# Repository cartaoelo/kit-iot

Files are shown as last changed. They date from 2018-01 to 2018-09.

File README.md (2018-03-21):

# KIT ELO IOT

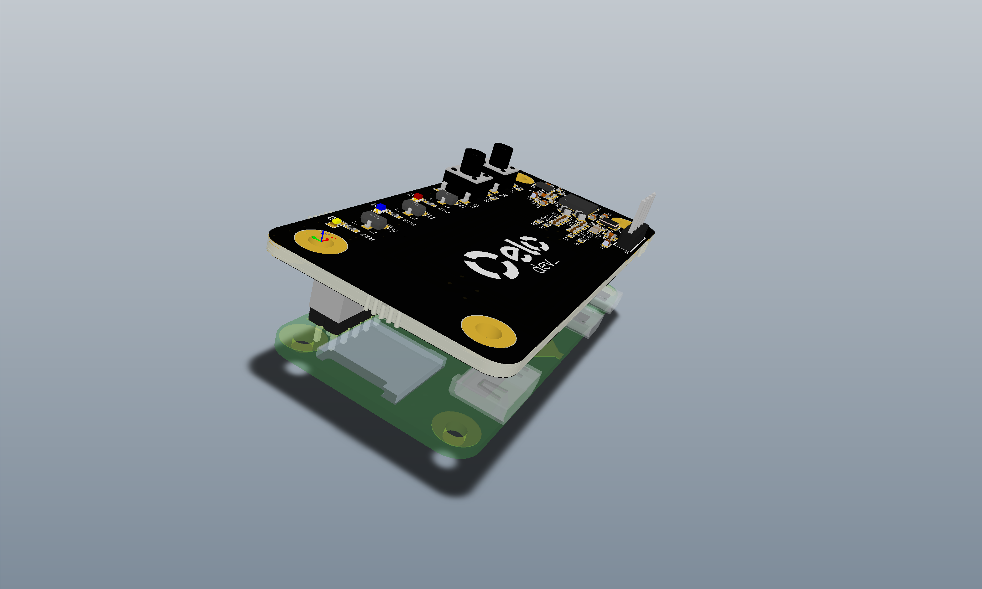
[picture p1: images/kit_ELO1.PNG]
Placa ELO + Raspberry Zero W

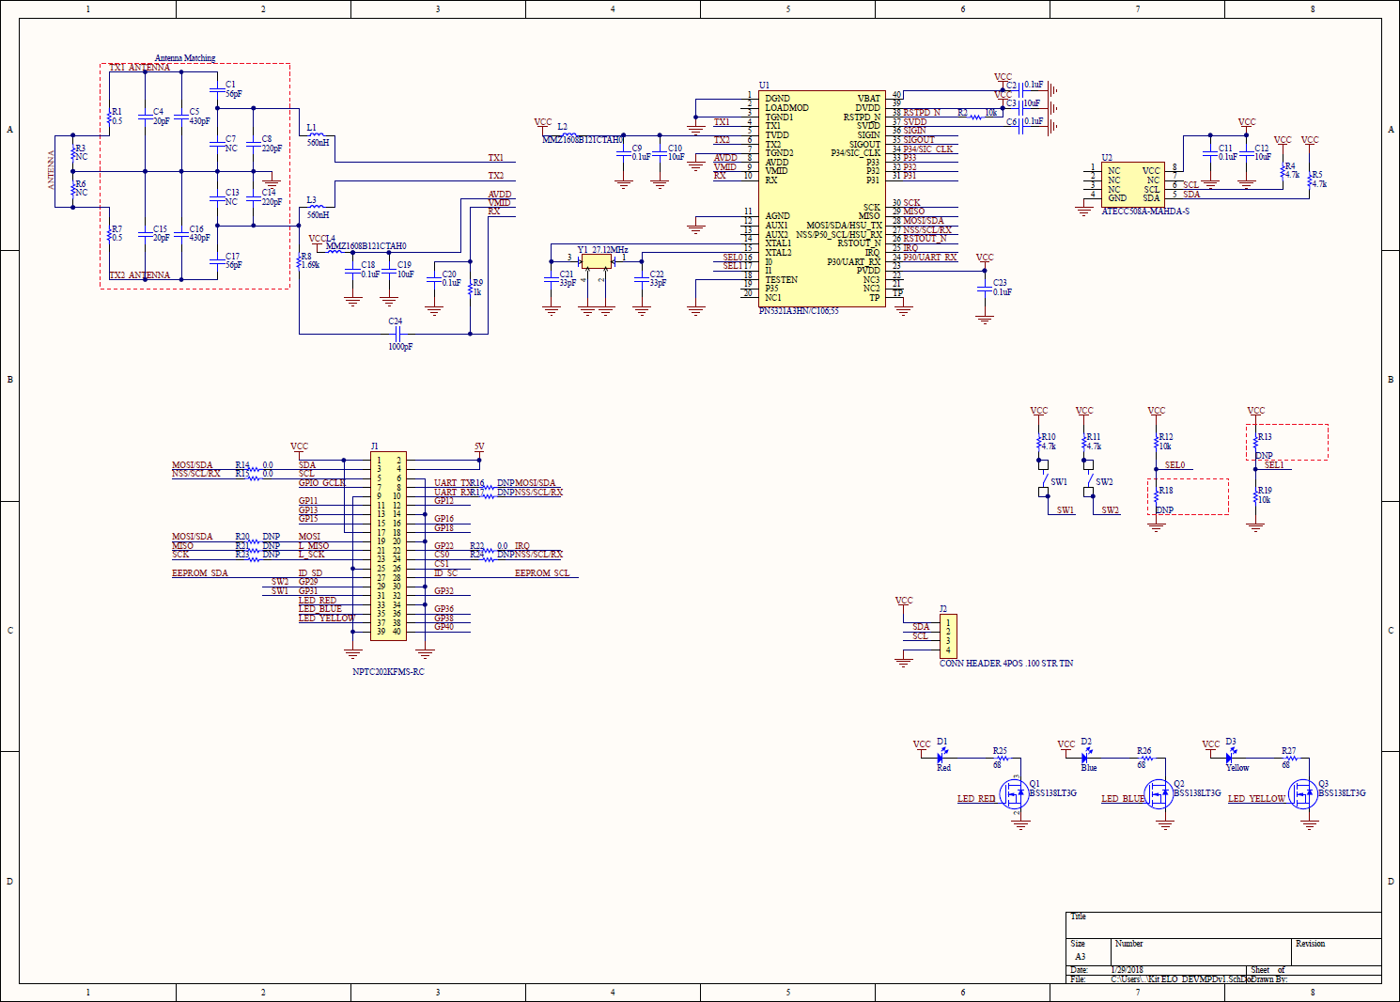
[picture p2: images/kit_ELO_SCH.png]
Placa ELO schematic


# PN532

**INTRODUÇÃO**

Este documento explica como utilizar o leitor NFC PN532 programando em Node.js.

### O que é NFC? 
>Near Field Communication
>É uma tecnologia que permite a troca de informações sem fio
>entre dispositivos, sendo necessária apenas uma aproximação
>física. A novidade teve origem no padrão RFID (Radio Frequency 
>Identification), mas se distanciou deste ao limitar o campo de 
>atuação de freqüências para uma distância de até 10 centímetros,
> objetivando tornar-se mais segura.

**ARQUIVOS NECESSÁRIOS**

Será necessário baixar a biblioteca modificada no github da elo-dev.

```sh
pi@raspberrypi:~ $ git clone https://github.com/cartaoelo/kit-iot.git
```

**INSTALAÇÃO**

O nodejs já vem instalado na raspberry em algumas imagens disponíveis no site do fabricante. Caso a versão do sistema operacional não possua o software instalado, deverá ser feita a instalação. Depois de instalar o nodejs, devemos instalar os pacotes npm necessários para que o exemplo funcione.
```sh
pi@raspberrypi:~ $ sudo apt-get install nodejs
pi@raspberrypi:~/kit-iot $ npm install --save
```

**DETECTANDO O PN532**

O PN532 será utilizado com comunicação i2c ligado no barramento padrão da raspberry  /dev/i2c-1. Para detectar o PN532 no barramento i2c será instalado o software i2c-tools. 

```sh
pi@raspberrypi:~ $ sudo apt-get install i2c-tools 
pi@raspberrypi:~ $ i2cdetect -y 1
    0  1  2  3  4  5  6  7  8  9  a  b  c  d  e  f
00:          -- -- -- -- -- -- -- -- -- -- -- -- --
10: -- -- -- -- -- -- -- -- -- -- -- -- -- -- -- --
20: -- -- -- -- 24 -- -- -- -- -- -- -- -- -- -- --
30: -- -- -- -- -- -- -- -- -- -- -- -- -- -- -- --
40: -- -- -- -- -- -- -- -- -- -- -- -- -- -- -- --
50: -- -- -- -- -- -- -- -- -- -- -- -- -- -- -- --
60: 60 -- -- -- -- -- -- -- -- -- -- -- -- -- -- --
70: -- -- -- -- -- -- -- -- 
```

O endereço i2c do PN532 é 0x24, o outro endereço exibido no log do comando é o chip de autenticação ATECC508A também instalado no kit-iot da ELO.

**EXEMPLO**

Depois de clonar o diretório do projeto, basta rodar o código exemplo.
```sh
pi@raspberrypi:~/kit-iot $ node example.js
READY
Firmware:  { IC: 50, Ver: 1, Rev: 6, Support: 7 }
Listen for card read event ...
1516380276255 'UID:' '04:96:a5:89:ba:53:5b'
1516380276583 'UID:' '04:96:a5:89:ba:53:5b'
1516380276875 'UID:' '04:96:a5:89:ba:53:5b'
1516380277164 'UID:' '04:96:a5:89:ba:53:5b' 
```

# ATECC508A - CONFIGURAÇÃO

**INTRODUÇÃO**

Este documento explica como utilizar o software Cryptotronix EClet para configurar o chip Atmel ATECC508A em uma raspberry pi.

**ARQUIVOS NECESSÁRIOS**

Será necessário o download do driver:
https://github.com/cryptotronix/EClet

```sh
 pi@raspberrypi:~ $ git clone https://github.com/cryptotronix/EClet.git
```

**INSTALAÇÃO**

Instale build-essential, autotools-dev, automake, autoconf, libtool, libxml2-dev, check, texinfo, and libgcrypt (libgcrypt11-dev on Debian variants)

```sh
pi@raspberrypi:~ $ sudo apt-get install build-essential autotools-dev automake autoconf libtool libxml2-dev check texinfo libgcrypt11-dev
```

Após isso rode o arquivo ./autogen.sh . 

Isso irá gerar o arquivo README necessário a partir do arquivo README.md assim como a versão beta requerida da biblioteca baixada anteriormente.

```sh
pi@raspberrypi:~ $ sudo ./autogen.sh
pi@raspberrypi:~ $ sudo make install
```

**CONFIGURAÇÔES INICIAIS**

Você tera que ter acesso ao barramento i2c da Raspberry ` /dev/i2c* `. 

É possível mudar isto adicionando seu usuário para o grupo I2C utilizando: `sudo usermod -aG i2c user ` ou ` sudo chmod o+rw /dev/i2c* ` .

Lista de comandos:

**eclet state** : verifica se está em estado de fábrica.

```sh
pi@raspberrypi:~ $ eclet state
Factory 
```

**eclet  personalize** : em caso de sucesso este comando não retorna nada, sua função é configurar todos os slots (0-16) para a chave privada. 

O slot 8 é reservado para uso futuro. 

```sh
pi@raspberrypi:~ $ eclet personalize 
pi@raspberrypi:~ $ eclet state 
Personalized
```

**eclet  random** : Até que você tenha personalizado o seu dispositivo, o gerador de número aleatório irá retornar um número com padrões contendo FF e 00. 

```sh
pi@raspberrypi:~ $ eclet random
7E74FBFE17A10026124B092C9727416D6C28B38FA5D598E0711A9FCDFCDEC408 
```

**eclet  serial-num** : Retorna o serial do dispositivo.

```sh
pi@raspberrypi:~ $ eclet serial-num
0123XXXXXXXXXXXXEE
```

**eclet  gen-key** : Irá criar uma chave privada com 256 bits e irá retornar uma chave pública de formato 0x04 + X +Y. 

Caso o comando seja dado mais vezes a chave pública irá ser alterada.

```sh
pi@raspberrypi:~ $ eclet gen-key
042A02563C69C4CB5356BD8BBA96B1559D5FE799B6C497B128F42F8CB31FF751BF40361F0970DF48979B3E18A1039047299A1C3D7B809EAA2F844F0D75C479BDB9
```

**eclet  sign -f ChangeLog** : Cria uma assinatura ECDSA. 

O arquivo pode ser especificado com -f.

```sh
pi@raspberrypi:~/Eclet $ eclet sign -f ChangeLog 5D1BD52DD2294CA1518E2520CFBF518AD6DD48AA57978BCAF91919E51E5FE3CA2B1EFC8427AC7EC499DF340B197319545FCB``2A7F87D981F6712365CF3E6872B3
```

**eclet  verify** : Verifica a assinatura ECDSA usada no dispositivo. 

Se estiver correta, nada acontecerá, caso contrário é reportada uma mensagem de falha na verificação.

```sh
pi@raspberrypi:~/Eclet $ eclet verify -f ChangeLog -–signature 5D1BD52DD2294CA1518E2520CFBF518AD6DD48AA57978BCAF91919E51E5FE3CA2B1EFC8427AC7EC499DF340B197319545FCB2A7F87D981F6712365CF3E6872B3 -–public-key 04DD24F3770BD11A6A465F37D1D6CEEA58F8B8E1B85A5D3D665A0382BCBCDDC81321458F8A4FE5777BA0D508780A2476A23434B89BE2BBD5B8CF574348A15F1982
```

**eclet  offline-verify-sign** : Verifica a assinatura ECDSA usada, sem a necessidade do dispositivo. 

Se estiver correta, nada acontecerá, caso contrário é reportada uma mensagem de falha na verificação.

```sh
pi@raspberrypi:~/Eclet $ eclet offline-verify-sign -f ChangeLog -–signature 5D1BD52DD2294CA1518E2520CFBF518AD6DD48AA57978BCAF91919E51E5FE3CA2B1EFC8427AC7EC499DF340B197319545FCB2A7F87D981F6712365CF3E6872B3 -–public-key 04DD24F3770BD11A6A465F37D1D6CEEA58F8B8E1B85A5D3D665A0382BCBCDDC81321458F8A4FE5777BA0D508780A2476A23434B89BE2BBD5B8CF574348A15F1982
```

**OPÇÕES**

As opções podem ser visualizadas utilizando o comando –-help .

**LICENÇA**

Este produto é _**open source**_ de software distribuído sob a licença GPLv3 e hardware sob a licença CERN OHL v1.2!

EClet foi escrito por Cryptotronix, e distribuído sob licença GPLv3.

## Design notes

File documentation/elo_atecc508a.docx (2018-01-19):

ATECC508A

# INTRODUÇÃO

Este documento explica como utilizar o software Cryptotronix EClet para configurar o chip Atmel ATECC508A em uma raspberry pi.

# ARQUIVOS NECESSÁRIOS

Será necessário o download do driver:

https://github.com/cryptotronix/EClet

pi@raspberrypi:~ $ git clone https://github.com/cryptotronix/EClet.git

INSTALAÇÃO

Instale build-essential, autotools-dev, automake, autoconf, libtool, libxml2-dev, check, texinfo, and libgcrypt (libgcrypt11-dev on Debian variants)

pi@raspberrypi:~ $ sudo apt-get install build-essential autotools-dev automake autoconf libtool libxml2-dev check texinfo libgcrypt11-dev

Após isso rode o arquivo ./autogen.sh . Isso irá gerar o arquivo README necessário a partir do arquivo README.md assim como a versão beta requerida da biblioteca baixada anteriormente.

pi@raspberrypi:~ $ sudo ./autogen.sh

pi@raspberrypi:~ $ sudo make install

# CONFIGURAÇÔES INICIAIS

Inicialmente é necessário executar /dev/i2c* para o acesso. É possível mudar isto adicionando seu usuário para o grupo I2C utilizando: sudo usermod -aG i2c user ou sudo chmod o+rw /dev/i2c* .

Existem alguns comandos suportados:

eclet state : verifica se está em estado de fábrica.

pi@raspberrypi:~ $ eclet state

Factory

eclet personalize : em caso de sucesso este comando não retorna nada, sua função é configurar todos os slots (0-16) para a chave privada. O slot 8 é reservado para uso futuro.

pi@raspberrypi:~ $ eclet personalize

pi@raspberrypi:~ $ eclet state

Personalized

eclet random : Até que você tenha personalizado o seu dispositivo, o gerador de número aleatório irá retornar um número com padrões contendo FF e 00.

pi@raspberrypi:~ $ eclet random

7E74FBFE17A10026124B092C9727416D6C28B38FA5D598E0711A9FCDFCDEC408

eclet serial-num : Retorna o serial do dispositivo.

pi@raspberrypi:~ $ eclet serial-num

0123XXXXXXXXXXXXEE

eclet gen-key : Irá criar uma chave privada com 256 bits e irá retornar uma chave pública de formato 0x04 + X +Y. Caso o comando seja dado mais vezes a chave pública irá ser alterada.

pi@raspberrypi:~ $ eclet gen-key

042A02563C69C4CB5356BD8BBA96B1559D5FE799B6C497B128F42F8CB31FF751BF40361F0970DF48979B3E18A1039047299A1C3D7B809EAA2F844F0D75C479BDB9

eclet sign -f ChangeLog : Cria uma assinatura ECDSA. O arquivo pode ser especificado com -f.

pi@raspberrypi:~/Eclet $ eclet sign -f ChangeLog

5D1BD52DD2294CA1518E2520CFBF518AD6DD48AA57978BCAF91919E51E5FE3CA2B1EFC8427AC7EC499DF340B197319545FCB2A7F87D981F6712365CF3E6872B3

eclet verify : Verifica a assinatura ECDSA usada no dispositivo. Se estiver correta, nada acontecerá, caso contrário uma mensagem de falha na verificação acontecerá.

pi@raspberrypi:~/Eclet $ eclet verify -f ChangeLog -–signature 5D1BD52DD2294CA1518E2520CFBF518AD6DD48AA57978BCAF9191

9E51E5FE3CA2B1EFC8427AC7EC499DF340B197319545FCB2A7F87D981F6712365CF3E6872B3 -–public-key 04DD24F3770BD11A6A465F37D1D6CEEA58F8B8E

1B85A5D3D665A0382BCBCDDC81321458F8A4FE5777BA0D508780A2476A23434B89BE2BBD5B8CF574348A15F1982

eclet offline-verify-sign : Verifica a assinatura ECDSA usada, sem a necessidade do dispositivo. Se estiver correta, nada acontecerá, caso contrário uma mensagem de falha na verificação acontecerá.

pi@raspberrypi:~/Eclet $ eclet offline-verify-sign -f ChangeLog -–signature 5D1BD52DD2294CA1518E2520CFBF518AD6DD48AA

57978BCAF91919E51E5FE3CA2B1EFC8427AC7EC499DF340B197319545FCB2A7F87D981F6712365CF3E6872B3 -–public-key 04DD24F3770BD11A6A465F37D1

D6CEEA58F8B8E1B85A5D3D665A0382BCBCDDC81321458F8A4FE5777BA0D508780A2476A23434B89BE2BBD5B8CF574348A15F1982

# OPÇÕES

As opções podem ser visualizadas utilizando o comando –-help .

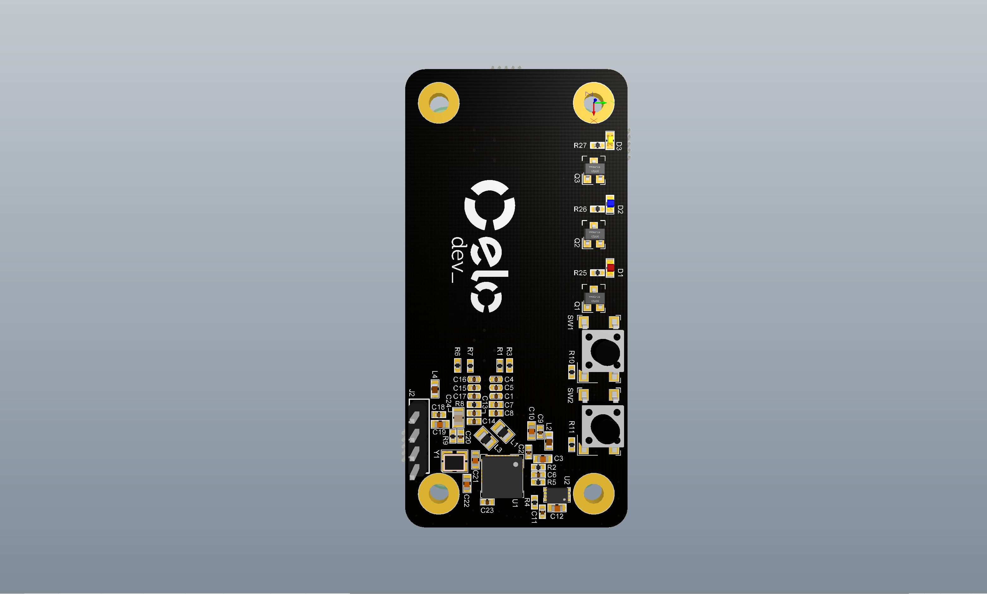
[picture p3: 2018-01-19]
images/kit_ELO2.PNG

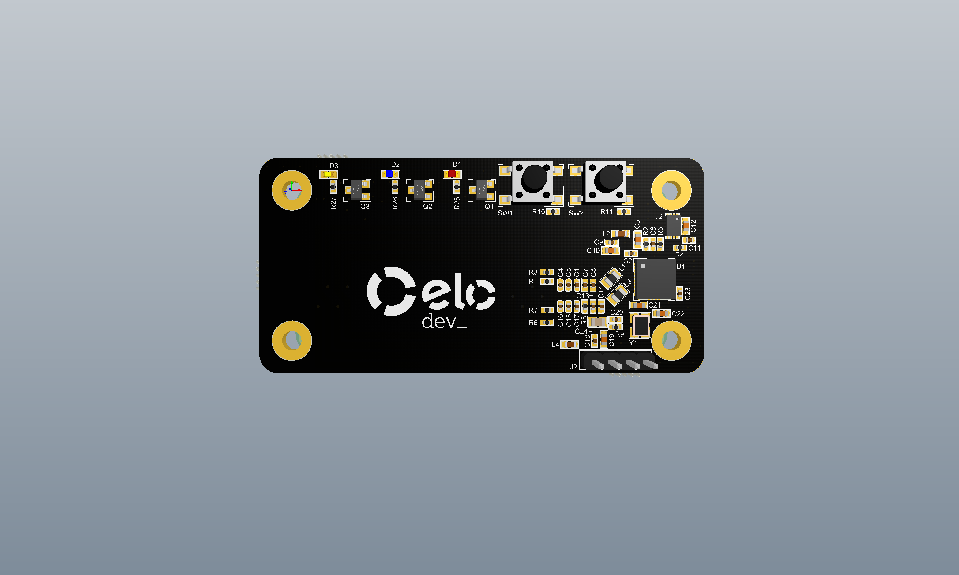
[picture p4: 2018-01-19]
images/kit_ELO3.PNG

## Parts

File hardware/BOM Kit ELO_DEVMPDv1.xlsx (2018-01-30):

Quantity | Designator | Description | Comment | Manufacturer | Manufacturer Part Number
2 | C1, C17 | CAP CER 56PF 50V C0G/NP0 0402 | 56pF | Vishay Vitramon | VJ0402D560JXAAJ
7 | C2, C6, C9, C11, C18, C20, C23 | CAP CER 0.1UF 10V X5R 0402 | 0.1uF | Murata Electronics North America | GRM155R61A104KA01D
4 | C3, C10, C12, C19 | CAP CER 10UF 16V X5R 0603 | 10uF | Murata Electronics North America | GRM188R61C106KAALD
2 | C4, C15 | CAP CER 20PF 50V C0G/NP0 0402 | 20pF | KEMET | C0402C200J5GACTU
2 | C5, C16 | CAP CER 430PF 50V C0G/NP0 0402 | 430pF | Murata Electronics North America | GRM1555C1H431GA01D
2 | C7, C13 | NC | NC | Murata Electronics North America | GRM155R61A104KA01D
2 | C8, C14 | CAP CER 220PF 50V C0G/NP0 0402 | 220pF | Samsung Electro-Mechanics | CL05C221JB5NNNC
2 | C21, C22 | CAP CER 33PF 50V C0G/NP0 0603 | 33pF | Murata Electronics North America | GRM1885C1H330JA01D
1 | C24 | CAP CER 1000PF 50V C0G/NP0 0805 | 1000pF | AVX Corporation | 08055A102GAT2A
1 | D1 | LED RED CLEAR 0603 SMD | Red | Lite-On Inc. | LTST-C190EKT
1 | D2 | LED BLUE CLEAR 0603 SMD | Blue | Lite-On Inc. | LTST-C193TBKT-5A
1 | D3 | LED YELLOW CLEAR 0603 SMD | Yellow | Lite-On Inc. | LTST-C191KSKT
1 | J1 | CONN FEMALE 40POS DL .1" TIN SMD | NPTC202KFMS-RC | Sullins Connector Solutions | NPTC202KFMS-RC
1 | J2 | CONN HEADER 4POS .100 STR TIN | CONN HEADER 4POS .100 STR TIN | Amphenol FCI | 68002-404HLF
2 | L1, L3 | FIXED IND 560NH 240MA 3.1 OHM | 560nH | Pulse Electronics Network | PE-0805CM561JTT
2 | L2, L4 | FERRITE BEAD 120 OHM 0603 1LN | MMZ1608B121CTAH0 | TDK Corporation | MMZ1608B121CTAH0
3 | Q1, Q2, Q3 | MOSFET N-CH 50V 200MA SOT-23 | BSS138LT3G | ON Semiconductor | BSS138LT3G
2 | R1, R7 | RES 0.5 OHM 1% 1/16W 0402 | 0.5 | Yageo | RL0402FR-070R5L
3 | R2, R12, R19 | RES SMD 10K OHM 1% 1/16W 0402 | 10k | Yageo | RC0402FR-0710KL
2 | R3, R6 | NC | NC | Yageo | RC0402FR-0710KL
4 | R4, R5, R10, R11 | RES SMD 4.7K OHM 5% 1/10W 0402 | 4.7k | Panasonic Electronic Components | ERJ-2GEJ472X
1 | R8 | RES SMD 1.69K OHM 1% 1/16W 0402 | 1.69k | Yageo | RC0402FR-071K69L
1 | R9 | RES SMD 1K OHM 5% 1/16W 0402 | 1k | Yageo | RC0402JR-071KL
8 | R13, R16, R17, R18, R20, R21, R23, R24 | RES SMD 0.0OHM JUMPER 1/16W 0402 | DNP | Rohm Semiconductor | MCR01MZPJ000
3 | R14, R15, R22 | RES SMD 0.0OHM JUMPER 1/16W 0402 | 0.0 | Rohm Semiconductor | MCR01MZPJ000
3 | R25, R26, R27 | RES SMD 68 OHM 5% 1/10W 0402 | 68 | Panasonic Electronic Components | ERJ-2GEJ680X
2 | SW1, SW2 | SWITCH TACTILE SPST-NO 0.05A 12V | PTS645SL50SMTR92 LFS | C&K | PTS645SL50SMTR92 LFS
1 | U1 | IC NFC NEAR FIELD CTLR 40HVQFN | PN5321A3HN/C106;55 | NXP USA Inc. | PN5321A3HN/C106;55
1 | U2 | AUTHENTICATION CHIP I2C 8-UDFN | ATECC508A-MAHDA-S | Microchip Technology | ATECC508A-MAHDA-S
1 | Y1 | CRYSTAL 27.1200MHZ 10PF SMD | 27.12MHz | TXC CORPORATION | 7M-27.120MEEQ-T

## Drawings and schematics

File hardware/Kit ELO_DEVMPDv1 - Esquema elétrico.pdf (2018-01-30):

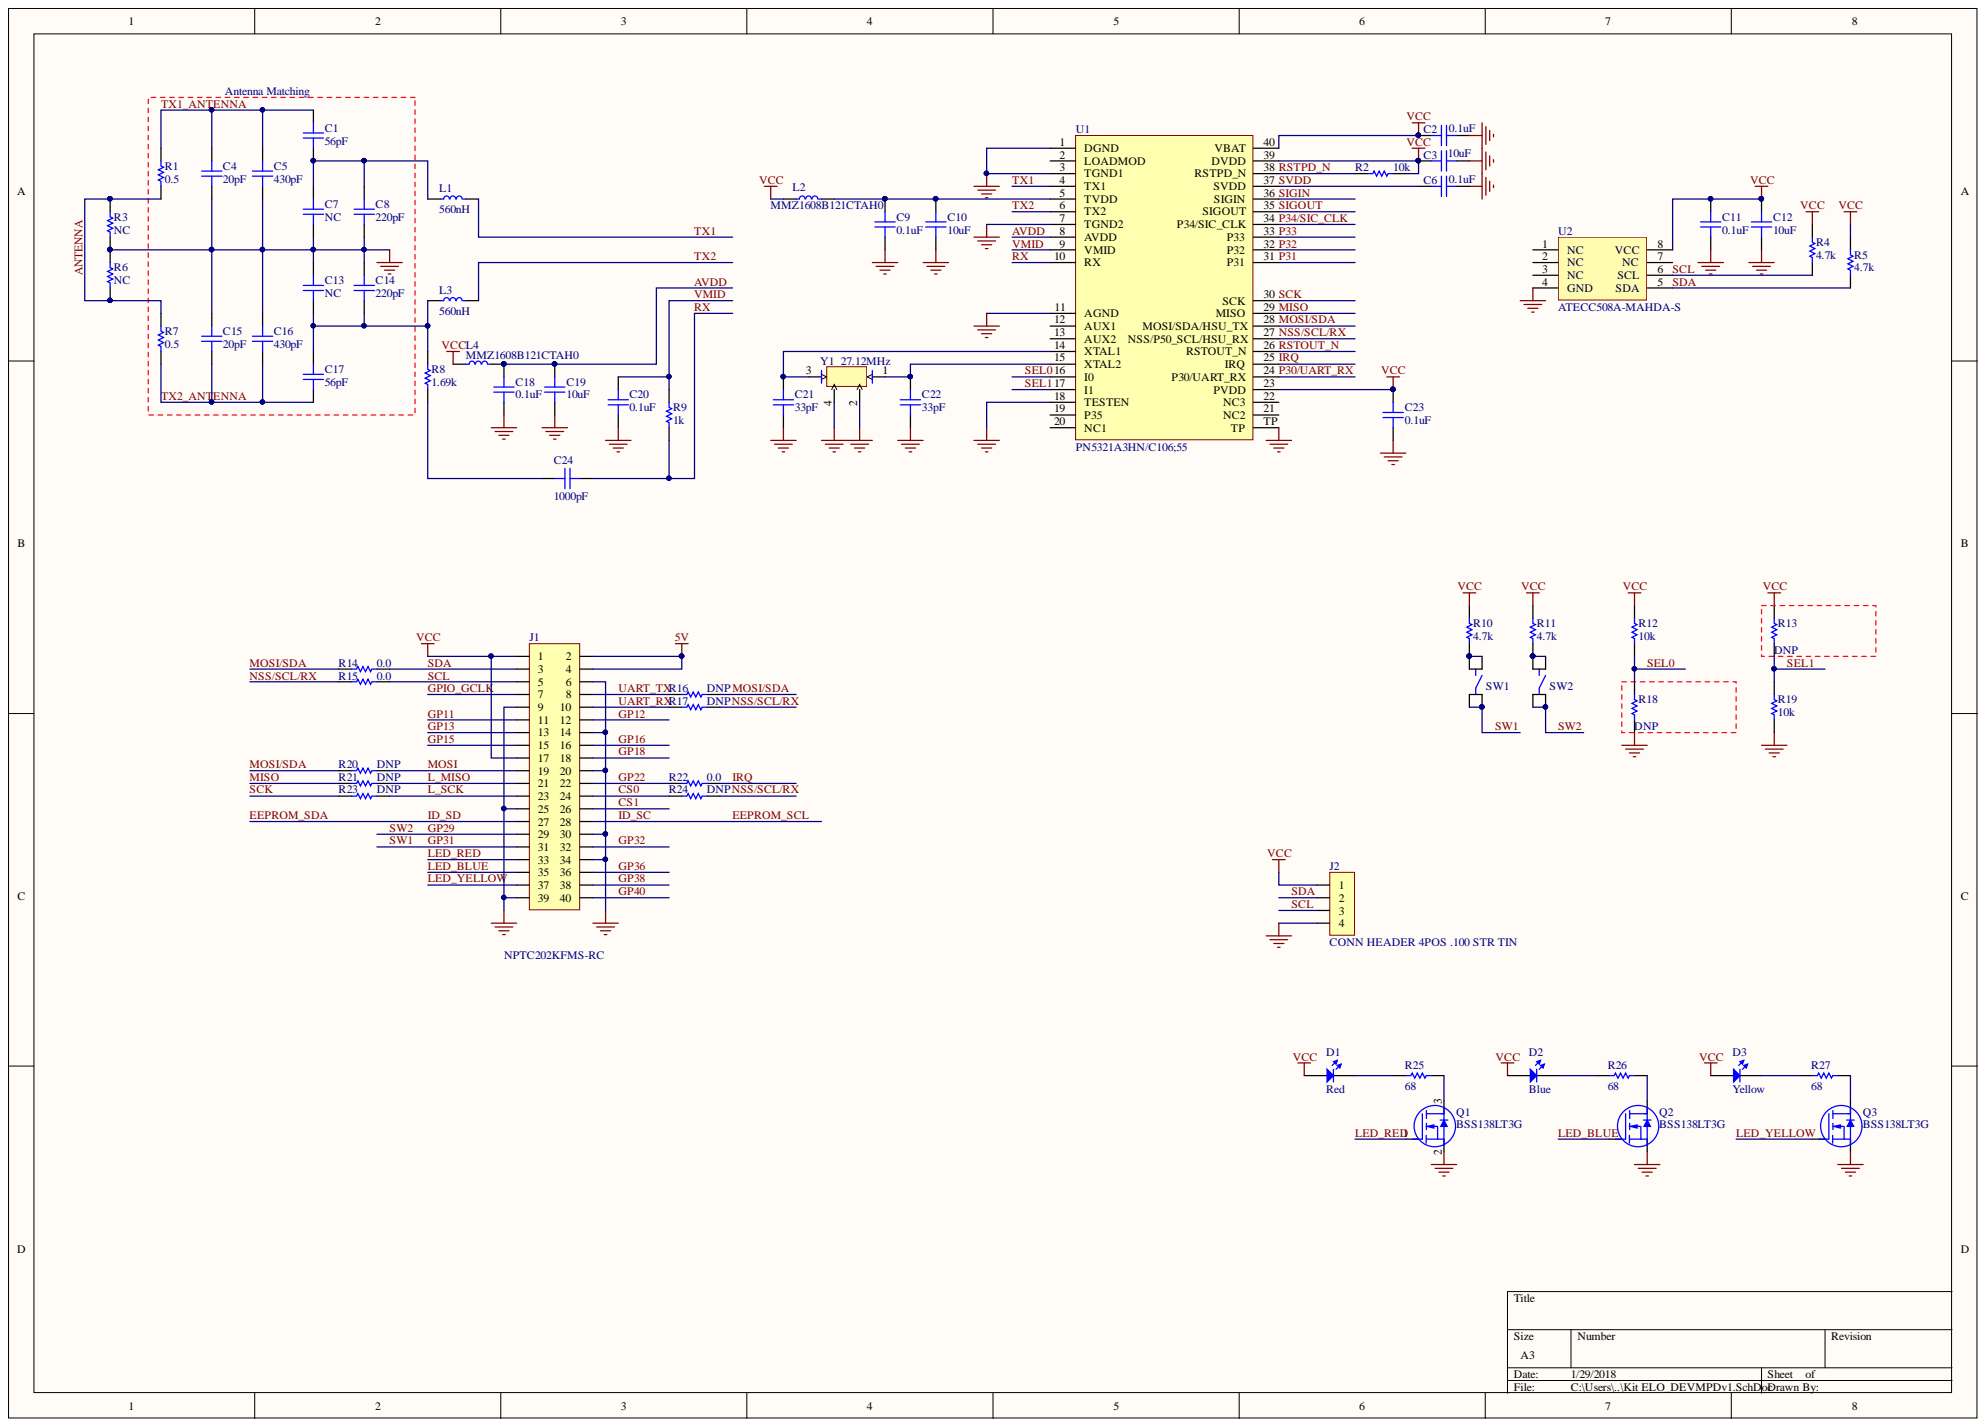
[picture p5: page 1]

SEL1 | I1 17 TESTEN 18

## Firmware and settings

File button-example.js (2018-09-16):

const Gpio = require('onoff').Gpio;

const sw1 = new Gpio(6, 'in', 'falling', {debounceTimeout: 200});
const sw2 = new Gpio(5, 'in', 'both');
const led = {
    red: new Gpio(13, 'out'),
    blue: new Gpio(19, 'out'),
    yellow: new Gpio(26, 'out')
};

let state_sw1 = 0;

sw1.watch(function (err, value) {
    if (err) {        
        console.log("Switch 1 ERROR", err);
    } else {
        state_sw1 = state_sw1 === 0 ? 1 : 0;
        led["red"].writeSync(state_sw1);
        led["blue"].writeSync(state_sw1);
        led["yellow"].writeSync(state_sw1);
    }
});

sw2.watch(function (err, value) {
    if (err) {        
        console.log("Switch 2 ERROR", err);
    } else {
        led["red"].writeSync(value);
        led["blue"].writeSync(value);
        led["yellow"].writeSync(value);
    }
});

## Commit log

2018-01-30 Add Hardware Files
    [BOM Kit ELO_DEVMPDv1.xlsx, Kit ELO_DEVMPDv1.PrjPcb, Kit ELO_DEVMPDv1.SchDoc]
2018-01-30 Add schematic image to README.md
2018-09-16 Add button and led examples
